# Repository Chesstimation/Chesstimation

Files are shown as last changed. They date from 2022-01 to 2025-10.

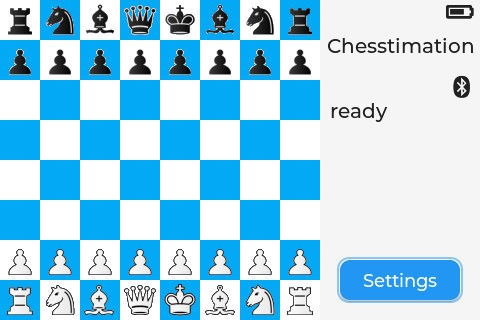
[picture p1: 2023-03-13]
images/main-screen.jpg

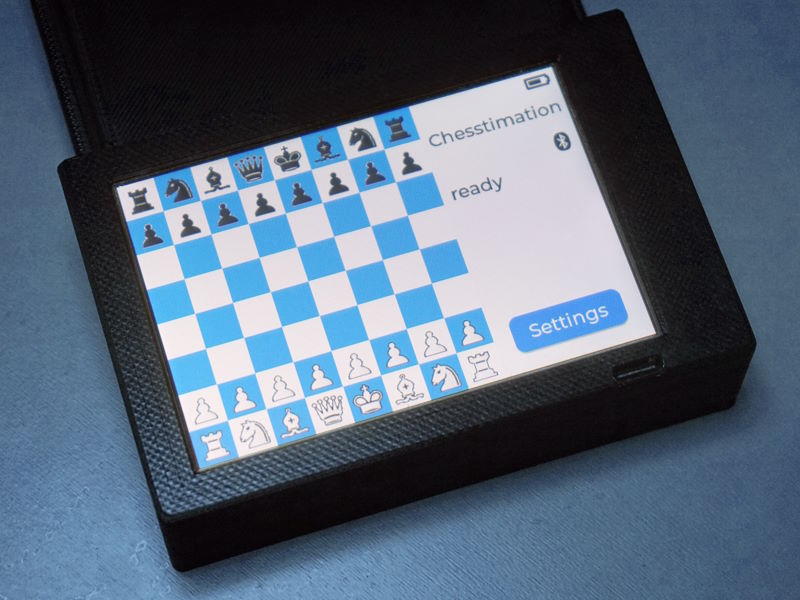
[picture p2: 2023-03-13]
images/module-detail.jpg

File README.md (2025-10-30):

**English** | [Deutsch](./README_de.md) |

# Chesstimation

This project uses ESP32 hardware to connect an old Hegener+Glaser Mephisto Modular chess computer (Modular, Exclusive or München Board) to a computer or a smart phone.

## Main Features:

* No modification to original Mephisto Modular/Exclusive/München board required. Just replace the old modules with the new one!
* 3.5" Color-TFT (480x320 Pixels), available space is perfectly used.
* Modern, intuitive touch control
* Current position is shown on the display.
* Both White and Black can be played from the front.
* All opponent's moves are displayed via the board's LEDs.
* Power supply via built-in battery that can be charged via USB-C (with 2200 mAh lipo >7h running time, ~4h charging time). 
* Communication with PC via USB-C, Bluetooth Classic or BLE (Bluetooth Low Energy).
* Playing completely without cables is possible!
* All settings and the board position are not lost when the device is switched off!
* Switching on and off takes less than 2 seconds.
* Certabo or Millennium Chesslink can be selected as emulation, making it compatible with many chess programs:
  * "White Pawn" on iPhone and Android (https://khadimfall.com/p/white-pawn)
  * "Chess for Android"
  * "Chess Dojo App" for Android
  * BearChess (http://www.solanosoft.com/index.php?page=bearchess)
  * original Certabo Software (https://www.certabo.com/)
  * Lucas Chess (https://lucaschess.pythonanywhere.com/index?lang=en)
  * and via Graham's DLLs (https://goneill.co.nz/chess.php) actually all software that can handle DGT boards.
* Pawn underpromotion selection when reaching second last row

## Limitations:

* Captured piece needs to be removed from board before capturing piece is put to the square. 
* Must not be combined with other modules or power supplies.

## Contact & Donation:

If you like this project you may contact me via chesstimation@kabelmail.de

I would also be happy to receive a donation. 



## Following hardware components are required:
1. Wemos LolinD32 (https://de.aliexpress.com/item/32808551116.html)
2. 40-pin edge card connector, e.g. https://de.aliexpress.com/item/33035971298.html (you need to select 2x20 Pin)
3. Rainbow Ribbon Cable (~30cm) with 1.27mm spacing, e.g. from Aliexpress: https://www.aliexpress.com/item/1005002509747445.html (you need to select 1.27mm spacing and 40 pin!)
4. Waveshare 3.5 inch TFT Pico Res Touch display: https://www.waveshare.com/pico-restouch-lcd-3.5.htm, e.g available here: https://eckstein-shop.de/WaveShare35inchTouchDisplayModuleforRaspberryPiPico2C65KColors2C480C3973202CSPI
5. Micro USB soldering plug (https://www.aliexpress.com/item/33060931097.html) and USB-C female soldering connector (e.g. https://www.aliexpress.com/item/1005002292881776.html) 
6. optionally lipo battery with plug for Lolin D32, e.g.: https://www.aliexpress.com/item/1005001310592871.html (you need an extra JST PH 2.0mm plug for this battery, e.g. https://www.aliexpress.com/item/1005001315857869.html Double-check polarity of plug with + and - signs on PCB of Lolin!) 
7. Micro-Switch (built into bottom of module) to switch off module completely (https://www.aliexpress.com/item/4001202080623.html Choose MSS-22D18 type!) 

## How to connect the 40-pin plug to the Mephisto board?

If you look at the chessboard or module from the front, the upper row of contacts is numbered from left to right from 1 to 39, the lower row from 2 to 40.
With the ribbon cable connector as linked above the wires are numbered a bit different, from left to right: 2,1, 4,3, 6,5, 8,7, ... 40,39.
This has already been considered in below table and you will be able to connect the 8 data wires just in parallel to the Lolin D32.

 <table>
  <tr>
    <th>40-pin Connector Pin</th>
    <th>LolinD32 Pin</th>
  </tr>
  <tr>
    <td>1+2</td>
    <td>BAT</td>
  </tr>
  <tr>
    <td>39+40</td>
    <td>GND</td>
  </tr>
  <tr>
    <td>15 / D0</td>
    <td>GPIO 12</td>
  </tr>
  <tr>
    <td>16 / D1</td>
    <td>GPIO 13</td>
  </tr>
  <tr>
    <td>17 / D2</td>
    <td>GPIO 27</td>
  </tr>
  <tr>
    <td>18 / D3</td>
    <td>GPIO 14</td>
  </tr>
  <tr>
    <td>19 / D4</td>
    <td>GPIO 25</td>
  </tr>
  <tr>
    <td>20 / D5</td>
    <td>GPIO 26</td>
  </tr>
  <tr>
    <td>21 / D6</td>
    <td>GPIO 32</td>
  </tr>
  <tr>
    <td>22 / D7</td>
    <td>GPIO 33</td>
  </tr>
  <tr>
    <td>29 / LDC_LE</td>
    <td>GPIO 2</td>
  </tr>
  <tr>
    <td>30 / ROW_LE</td>
    <td>GPIO 15</td>
  </tr>
  <tr>
    <td>31 / CB_EN</td>
    <td>GPIO 4</td>
  </tr>
  <tr>
    <td>32 / LDC_EN</td>
    <td>GPIO 0</td>
  </tr>
</table> 

## How to connect the 3.5" display to Lolin D32

 <table>
  <tr>
    <th>TFT Display Pin</th>
    <th>LolinD32 Pin</th>
  </tr>
  <tr>
    <td>VSYS</td>
    <td>BAT</td>
  </tr>
  <tr>
    <td>GND</td>
    <td>GND</td>
  </tr>
  <tr>
    <td>LCD_DC</td>
    <td>GPIO 17</td>
  </tr>
  <tr>
    <td>LCD_CS</td>
    <td>SS/GPIO 5</td>
  </tr>
  <tr>
    <td>CLK</td>
    <td>SCK/GPIO 18</td>
  </tr>
  <tr>
    <td>MOSI</td>
    <td>MOSI/GPIO 23</td>
  </tr>
  <tr>
    <td>MISO</td>
    <td>MISO/GPIO 19</td>
  </tr>
  <tr>
    <td>LCD_BL</td>
    <td>GPIO 16</td>
  </tr>
  <tr>
    <td>LCD_RST</td>
    <td>RST(RESET)</td>
  </tr>
  <tr>
    <td>TP_CS</td>
    <td>GPIO 21</td>
  </tr>
  <tr>
    <td>TP_IRQ</td>
    <td>GPIO 34</td>
  </tr>
</table> 

## Software development environment

Software development is done in C++ using:
* Visual Studio Code
* Platform IO

In Platform IO you need to install 2 additional libraries for this project:
* LVGL 8.3.4 (you need to use Chesstimation's lv_conf.h)
* TFT eSPI 2.5.2 (you need to use Chesstimation's as User_Setup.h and User_Setup_Select.h)

For flashing the firmware to the Lolin D32 without Platform IO I use ESP Flasher: https://github.com/Jason2866/ESP_Flasher/releases

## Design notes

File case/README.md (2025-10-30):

**English** | [Deutsch](./README_de.md) |

# 3D-printable case for Open Mephisto

In this directory you find five different STL file to print your Open Mephisto module and matching blank modules.

For the Open Mephisto Module I use:
* ...BASE.stl
* ...DISPLAY.stl
* ...COVER.stl

For each matching blank module I use:
* ...BASE.stl
* ...DISPLAY-VOID.stl
* ...COVER-SNAP.stl

## Print Settings:

* Material: PLA
* Slice thickness: 0.2 mm first slice, 0.15 mm all other slices
* Support needed for ...BASE.stl only

## Donation:

If you like this project, I would be happy to receive a donation. 



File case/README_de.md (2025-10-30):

**Deutsch** | [English](./README.md) |

# 3D-Druckdateien für Open Mephisto

Hier findet ihr fünf verschiedene Dateien um die Teile für das Modul und auch entsprechende Leermodule zu drucken.
Die Module passen in Modular-, Exclusive- und München-Bretter.

Für das eigentliche Modul verwende ich die folgenden 3 Dateien:
* ...BASE.stl
* ...DISPLAY.stl
* ...COVER.stl

Für Leermodule verwende ich die folgenden 3 Dateien:
* ...BASE.stl
* ...DISPLAY-VOID.stl
* ...COVER-SNAP.stl

## Druckeinstellungen:

* Material: PLA
* Schichtdicke ist 0,2 mm für die erste Schicht, für alle weiteren Schichten 0,15 mm
* Support Material wird nur für den Druck von ...BASE.stl benötigt.

## Spenden:

Falls euch das Projekt gefällt, würde ich mich über Spenden sehr freuen:



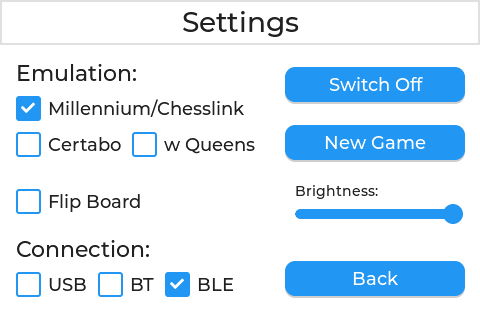
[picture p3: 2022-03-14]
images/settings-screen.jpg

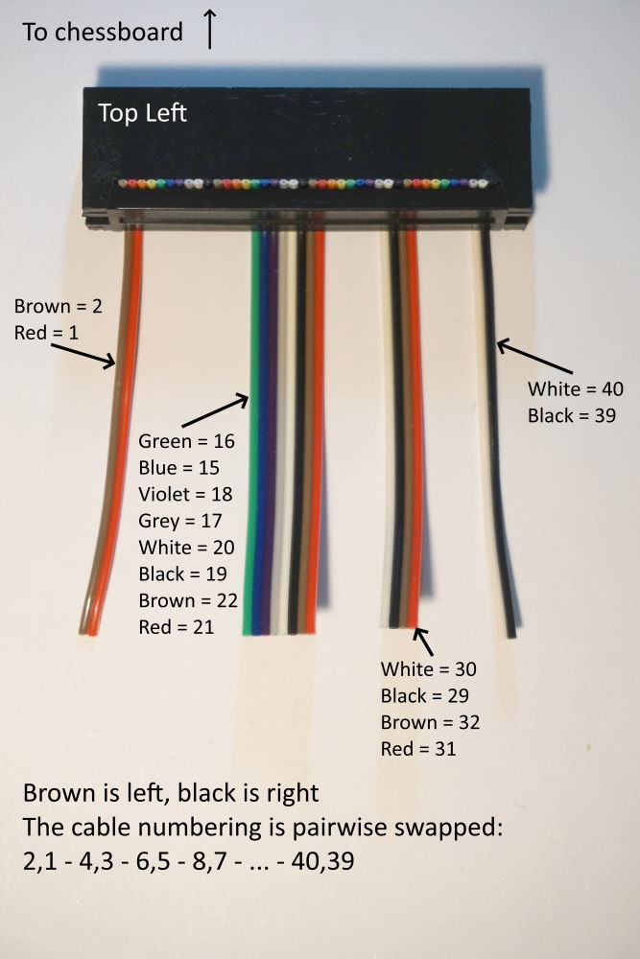
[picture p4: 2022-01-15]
images/40-pin-to-lolind32.jpg

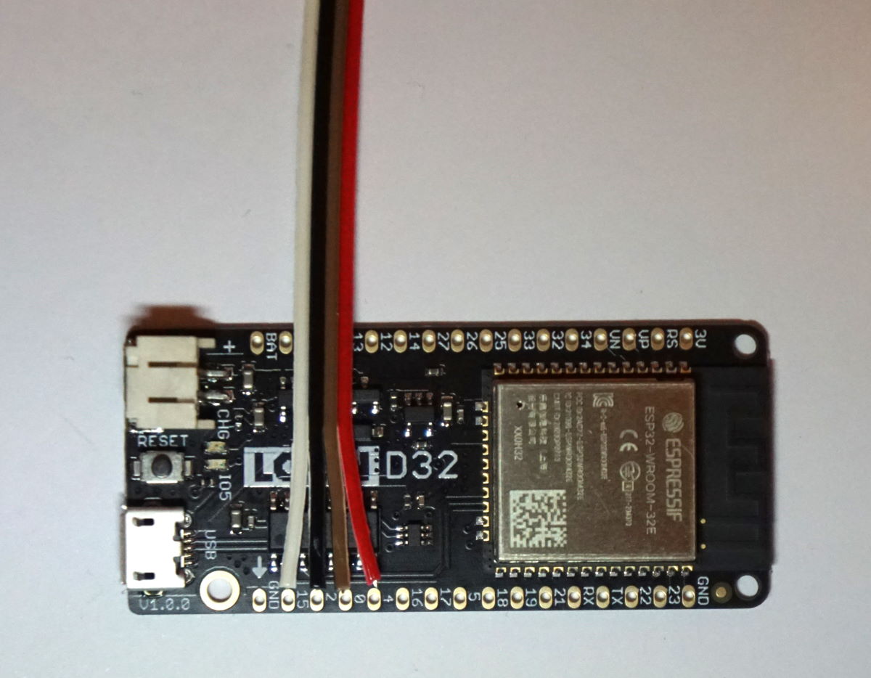
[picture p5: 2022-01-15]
images/control-to-lolinD32.jpg

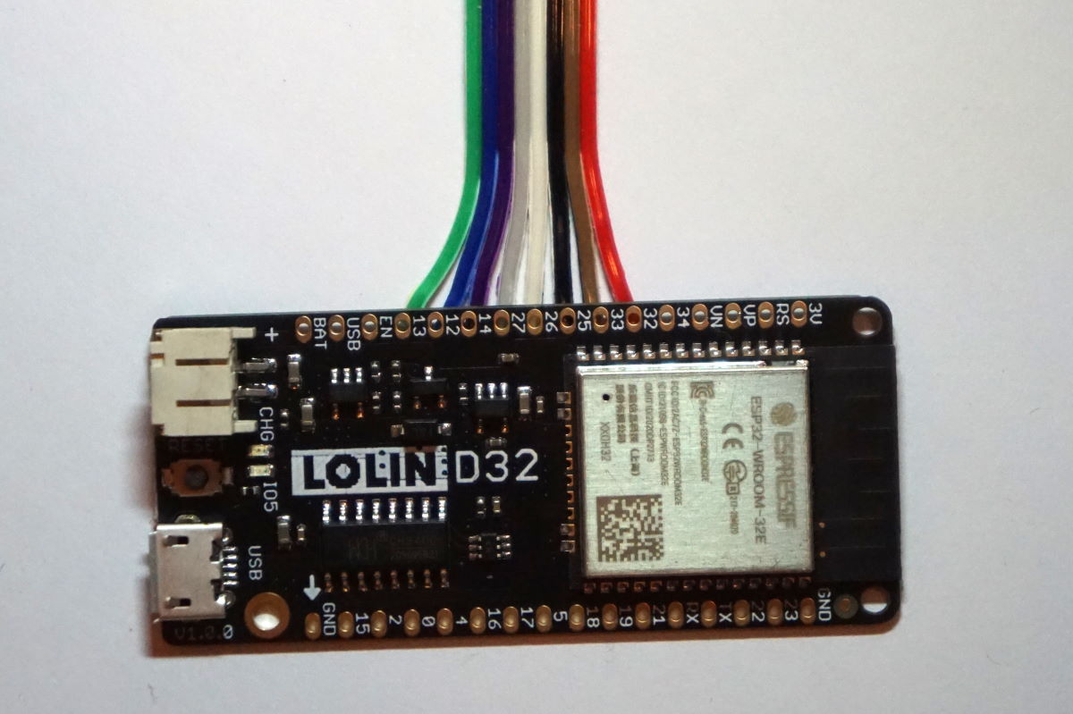
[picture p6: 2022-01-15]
images/data-to-lolinD32.jpg

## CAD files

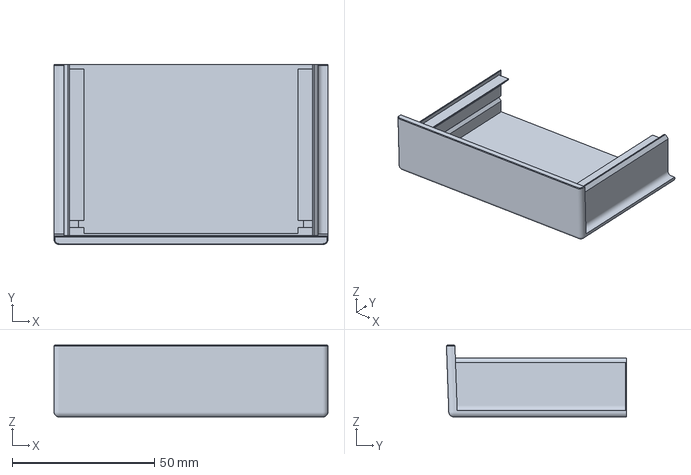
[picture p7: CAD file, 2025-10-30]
case/open-mephisto-module-tft-35-pi-pico-DISPLAY-VOID.3mf
96.4 x 63.4 x 25.3 mm

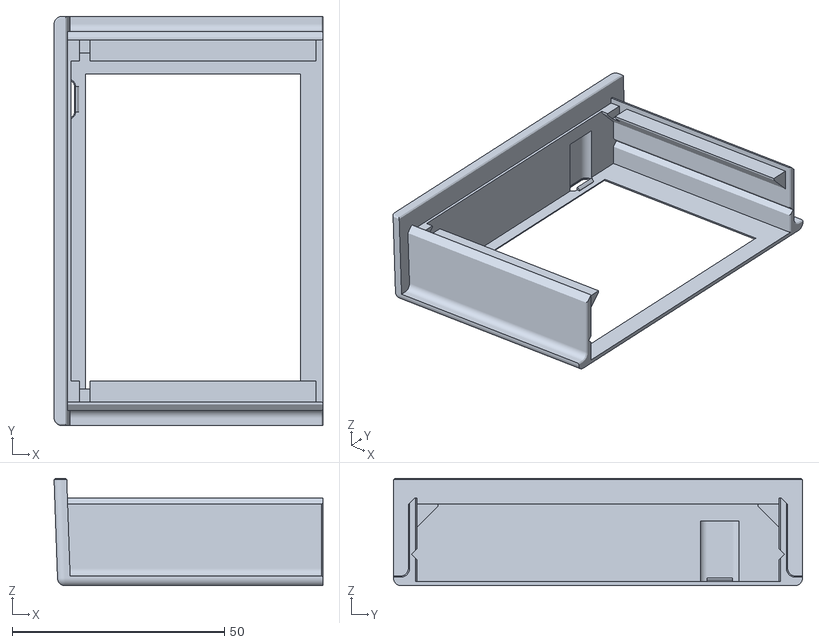
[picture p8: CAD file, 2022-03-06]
case/open-mephisto-module-tft-35-pi-pico-display.stl
63.4 x 96.4 x 25.3

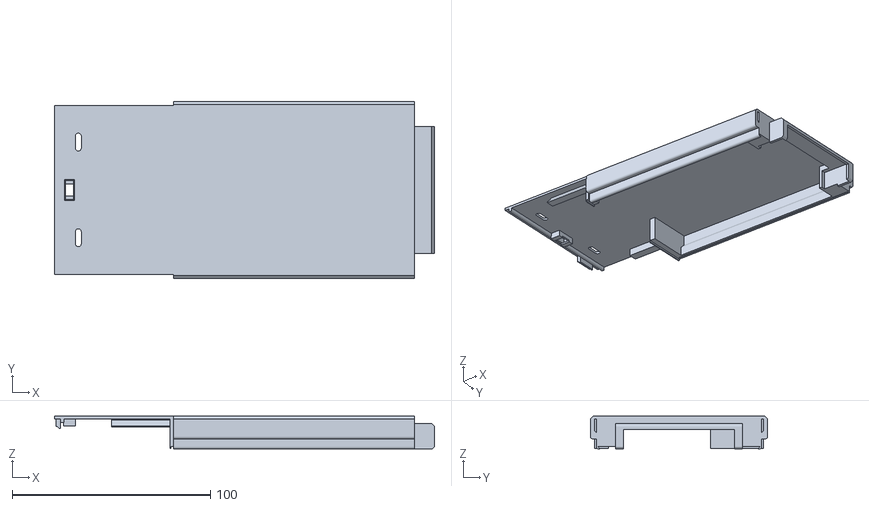
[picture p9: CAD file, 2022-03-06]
case/open-mephisto-module-tft-35-pi-pico-BASE.stl
191.5 x 89.4 x 16.6

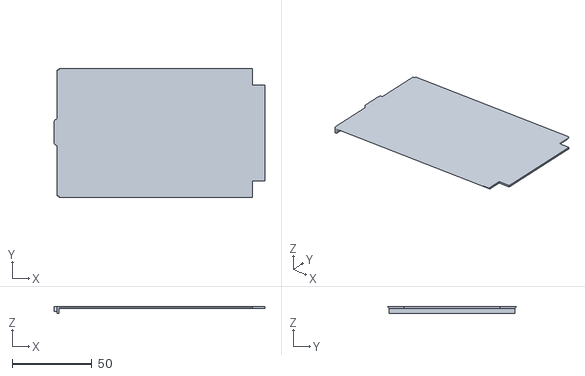
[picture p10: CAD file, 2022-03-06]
case/open-mephisto-module-tft-35-pi-pico-cover.stl
132.7 x 81.2 x 4.20

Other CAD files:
case/DISPLAY-VOID-normal.3mf
case/DISPLAY-VOID-fuzzy.3mf
case/open-mephisto-module-tft-35-pi-pico-COVER-SNAP.stl
case/open-mephisto-module-tft-35-pi-pico-DISPLAY-VOID.stl

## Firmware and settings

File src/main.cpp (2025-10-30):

/*  
    Copyright 2021, 2022, 2023, 2024, 2025 Andreas Petersik (andreas.petersik@gmail.com)
    
    This file is part of the Chesstimation Project.

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
    You should have received a copy of the GNU General Public License
    along with Chesstimation.  If not, see <https://www.gnu.org/licenses/>.
*/

#define VERSION     "Chesstimation 1.7.1"
#define ABOUT_TEXT  "\nby Dr. Andreas Petersik\nandreas.petersik@gmail.com\n\nbuilt: Oct 30th, 2025"
// #define BOARD_TEST

#include <Arduino.h>
#include <SPIFFS.h>
#include <esp_sleep.h>
#include <driver/rtc_io.h>
#include <driver/adc.h>
#include <BluetoothSerial.h>
#include "lv_i18n.h"

#include <BLEDevice.h>
#include <BLE2902.h>
#include "BLEHIDDevice.h"

// For emulations:
#include <thread>
#include <chrono>

// my includes:

#include <mephisto.h>
#include <board.h>

#include "SPI.h"
#include "TFT_eSPI.h"

#include "../lvgl/src/lvgl.h"

#define LOLIN_D32
#define LED_TIME 300
#define MIN_BRIGHTNESS 190

#define TOUCH_PANEL_IRQ_PIN   GPIO_NUM_34   // The idea is to check if there is a signal change on this pin for waking ESP32 from sleep! Works! Pin is high when no touch, low when touch!

#define BOARD_SETUP_FILE  "/board_setup"
#define SQUARE_SIZE         40

// #define PEGASUS

Mephisto mephisto;
Board chessBoard;
BluetoothSerial SerialBT;

char modeBleAdvertisedName[] = "MILLENNIUM CHESS";

int millBLEinitialized = 0;
int physicalConformity = 0;

enum connectionType {USB, BT, BLE} connection;  // Should be same order as in UI
enum languageType {EN, ES, DE} language;        // Should be same order as in UI

byte readRawRow[8];
byte led_buffer[8];
byte mephistoLED[8][8];
byte eeprom[5]={0,20,3,20,15};
byte LED_startup_sequence[64] = {0,1,2,3,4,5,6,7,15,23,31,39,47,55,63,62,61,60,59,58,57,56,48,40,32,24,16,8, 9,10,11,12,13,14,22,30,38,46,54,53,52,51,50,49,41,33,25,17, 18,19,20,21,29,37,45,44,43,42,34,26, 27,28,36,35};
byte oldBoard[64];
int brightness = 255;

uint16_t calibrationData[5];

//BLE objects
BLEServer *pServer = NULL;
BLECharacteristic *pTxCharacteristic;
BLEService *pService;

SemaphoreHandle_t sendBLEsemaphore = NULL;

char incomingMessage[170];
std::string replyString;

TFT_eSPI tft = TFT_eSPI();

/*Set to your screen resolution*/
#define TFT_HOR_RES   480
#define TFT_VER_RES   320

/*LVGL draw into this buffer, 1/10 screen size usually works well. The size is in bytes*/
#define DISP_BUF_SIZE (320 * 96)
// #define DISP_BUF_SIZE (320 * 60) // old size used for LVGL 8.x
// #define DISP_BUF_SIZE (TFT_HOR_RES * TFT_VER_RES / 6 * (LV_COLOR_DEPTH / 8)) // leads to not working White Pawn
// lv_color_t *dispBuf;//[DISP_BUF_SIZE]; 
void *dispBuf;//[DISP_BUF_SIZE]; 

lv_display_t * disp;

lv_style_t fMediumStyle;
lv_style_t fLargeStyle;
lv_style_t fExtraLargeStyle;
lv_style_t light_square;
lv_style_t dark_square;

LV_FONT_DECLARE(montserrat_umlaute20);
LV_FONT_DECLARE(montserrat_umlaute22);
LV_IMG_DECLARE(WP40);
LV_IMG_DECLARE(BP40);
LV_IMG_DECLARE(WK40);
LV_IMG_DECLARE(BK40);
LV_IMG_DECLARE(WB40);
LV_IMG_DECLARE(BB40);
LV_IMG_DECLARE(WQ40);
LV_IMG_DECLARE(BQ40);
LV_IMG_DECLARE(WN40);
LV_IMG_DECLARE(BN40);
LV_IMG_DECLARE(WR40);
LV_IMG_DECLARE(BR40);

lv_indev_t * indev;

lv_obj_t *settingsScreen, *settingsBtn, *btn2, *screenMain, *liftedPiecesLbl, *liftedPiecesStringLbl, *debugLbl, *chessBoardCanvas, *chessBoardLbl, *batteryLbl;
lv_obj_t *labelA1, *exitSettingsBtn, *offBtn, *certaboCalibCB, *restartBtn, *certaboCB, *chesslinkCB, *languageLbl, *flippedCB, *pegasusCB, *testCB;
lv_obj_t *square[64], *dummy1Btn, *calibrateBtn, *object, *brightnessSlider, *connectionLbl, *commLbl, *emulatorsBtn, *langBtn, *langLbl;
lv_obj_t *ui_settings_obj, *offBtnLbl, *newGameLbl, *brightLbl, *backLbl, *settingsLbl, *emulationLbl, *langDd, *connectionDd;
lv_obj_t *promotionBtnW, *promotionBtnImageW, *promotionBtnB, *promotionBtnImageB;
lv_obj_t *wp[8], *bp[8], *wk, *bk, *wn1, *bn1, *wn2, *bn2, *wb1, *bb1, *wb2, *bb2, *wr1, *br1, *wr2, *br2, *wq1, *bq1, *wq2, *bq2;

void displayLEDstartUpSequence()
{
  for(int i=0; i<64; i++)
  {
    mephisto.writeRow(getRowFromBoardIndex(LED_startup_sequence[i]), 0x1 << getColFromBoardIndex(LED_startup_sequence[i]));
    delay(48);
  }
}

void assembleIncomingChesslinkMessage(char readChar)
{
  switch (readChar)
  {
  case 'R':
  case 'I':
  case 'L':
  case 'V':
  case 'W':
  case 'S':
  case 'X':
    incomingMessage[0] = readChar;
    incomingMessage[1] = 0;
    break;
  default:
    byte position = strlen(incomingMessage);
    incomingMessage[position] = readChar;
    incomingMessage[position + 1] = 0;
    break;
  }
}

void displayAboutBox()
{
  object = lv_msgbox_create(screenMain);

  lv_msgbox_add_title(object, VERSION);
  lv_msgbox_add_text(object, ABOUT_TEXT);
  lv_msgbox_add_close_button(object);

  lv_obj_add_style(object, &fLargeStyle, 0);
  lv_obj_set_size(object, 368, 186);
  lv_obj_center(object);
  lv_obj_clear_flag(object, LV_OBJ_FLAG_SCROLLABLE);
}

byte debugPrint(const char *message)
{
  if(connection != USB) 
  {
    Serial.print(message);
    return 1;
  }
  if(connection != BT) 
  {
    SerialBT.print(message);
    return 1;
  }
  return 0;
}

void startTouchCalibration()
{
    // object = lv_msgbox_create(NULL, "Touch Calibration", "Touch the corners with the white line\nin counter clockwise order", NULL, true);

    // lv_obj_add_style(object, &fLargeStyle, 0);
    // lv_obj_set_size(object, 480, 320);
    // lv_obj_center(object);
    // lv_obj_clear_flag(object, LV_OBJ_FLAG_SCROLLABLE);

    tft.calibrateTouch(calibrationData, TFT_WHITE, TFT_RED, 15);
    tft.fillRect(480-16, 320-16, 16, 16, TFT_RED);

    lv_obj_invalidate(settingsScreen);

    // lv_obj_add_flag(object, LV_OBJ_FLAG_HIDDEN);
}

byte debugPrintln(const char *message)
{
  if(connection != USB) 
  {
    Serial.println(message);
    return 1;
  }
  if(connection != BT) 
  {
    SerialBT.println(message);
    return 1;
  }
  return 0;
}

void saveBoardSettings(void)
{
  connectionType saveConnection = USB;

  if (!SPIFFS.begin())
  {
    SPIFFS.format();
    SPIFFS.begin();
  }

  if ((connection == BLE) && (chessBoard.emulation != 0))
  {
    saveConnection = BLE;
  }
  if (connection == BT)
  {
    saveConnection = BT;
  }

  // store data
  File f = SPIFFS.open(BOARD_SETUP_FILE, "w");
  if (f)
  {
    f.write((const byte *)chessBoard.piece, 64);
    f.write((const byte *)chessBoard.piecesLifted, 64);
    f.write(chessBoard.liftedIdx);
    f.write(chessBoard.emulation);
    f.write(chessBoard.flipped);
    f.write(saveConnection);
    f.write(brightness);
    f.write(language);
    f.close();
  }
}

void loadBoardSettings(void)
{

  byte tempBoardSetup[64];
  uint16_t tempPiecesLifted[32];
  uint8_t tempInt8[1];
  physicalConformity = 1;

  if (!SPIFFS.begin())
  {
    SPIFFS.format();
    SPIFFS.begin();
  }

  // check if file exists
  if (SPIFFS.exists(BOARD_SETUP_FILE))
  {
    File f = SPIFFS.open(BOARD_SETUP_FILE, "r");
    if (f)
    {
      if (f.readBytes((char *)tempBoardSetup, 64) == 64)
      {
        for (int i = 0; i < 64; i++)
        {
          chessBoard.piece[i] = tempBoardSetup[i];
        }
      }
      if (f.readBytes((char *)tempPiecesLifted, 64) == 64)
      {
        for (int i = 0; i < 32; i++)
        {
          chessBoard.piecesLifted[i] = tempPiecesLifted[i];
        }
      }
      if (f.readBytes((char *)tempInt8, 1) == 1)
      {
        chessBoard.liftedIdx = tempInt8[0];
      }
      if (f.readBytes((char *)tempInt8, 1) == 1)
      {
        chessBoard.emulation = tempInt8[0];
      }
      if (f.readBytes((char *)tempInt8, 1) == 1)
      {
        chessBoard.flipped = tempInt8[0];
      }
      if (f.readBytes((char *)tempInt8, 1) == 1)
      {
        connection = (connectionType)tempInt8[0];
      }
      if (f.readBytes((char *)tempInt8, 1) == 1)
      {
        if(tempInt8[0] < MIN_BRIGHTNESS)
        {
          brightness = MIN_BRIGHTNESS;
        }
        else
        {
          brightness = tempInt8[0];
        }
      }
      if (f.readBytes((char *)tempInt8, 1) == 1)
      {
        language = (languageType)tempInt8[0];
      }
      f.close();
    }
  }
}

void updateMephistoLEDs(byte mephistoLED[8][8]) {
  for(byte row=0; row<8; row++) {
    for(byte col=0; col<8; col++) {
      mephistoLED[col][row]=chessBoard.milleniumLEDs[col][row] & chessBoard.milleniumLEDs[col+1][row]
        & chessBoard.milleniumLEDs[col][row+1] & chessBoard.milleniumLEDs[col+1][row+1];
    }
  }
}

byte getOddParity(byte value)
{
  value ^= value >> 4;
  value ^= value >> 2;
  value ^= value >> 1;
  return (~value) & 1;
}

void sendMessageToChessBoard(const char *message)
{
  std::string codedMessage = message;
  char blockCode[3];

  debugPrintln("Message to be sent from Board to Application: ");
  debugPrintln(message);

  if (chessBoard.emulation == 1)
  {
    sprintf(blockCode, "%02X", chessBoard.calcBlockPar(message));
    codedMessage += blockCode;
  }

  if (connection == BLE)
  {

    for (int i = 0; i < codedMessage.length(); i++)
    {
      if (getOddParity(codedMessage[i]))
      {
        codedMessage[i] += 128;
      }
    }
    // debugPrint("Final Message to be sent: ");
    // debugPrintln(codedMessage.c_str());

    if (xSemaphoreTake(sendBLEsemaphore, portMAX_DELAY) == pdTRUE)
    {
      for (int i = 0; i < codedMessage.length(); i += 8)
      {
        pTxCharacteristic->setValue(codedMessage.substr(i, 8));
        pTxCharacteristic->notify();
      }
      xSemaphoreGive(sendBLEsemaphore);
    }
    else
    {
      debugPrintln("*** Semaphore could not be taken - ERROR sending message ***");
    }
  }
  if (connection == BT)
  {
    SerialBT.print(codedMessage.c_str());
    SerialBT.flush();
  }
  if (connection == USB)
  {
    Serial.print(codedMessage.c_str());
    Serial.flush();
  }
}

void updateSettingsScreen()
{
  if(chessBoard.emulation==0) 
  {
#ifdef PEGASUS
    lv_obj_clear_state(pegasusCB, LV_STATE_CHECKED);  
#endif
    lv_obj_add_state(certaboCB, LV_STATE_CHECKED);
    lv_obj_clear_state(chesslinkCB, LV_STATE_CHECKED);  
  }
  if(chessBoard.emulation==1) 
  {
#ifdef PEGASUS
    lv_obj_clear_state(pegasusCB, LV_STATE_CHECKED);  
#endif
    lv_obj_clear_state(certaboCB, LV_STATE_CHECKED);
    lv_obj_add_state(chesslinkCB, LV_STATE_CHECKED);  
  }
  if(chessBoard.emulation==2) 
  {
    lv_obj_clear_state(certaboCB, LV_STATE_CHECKED);
    lv_obj_clear_state(chesslinkCB, LV_STATE_CHECKED);
#ifdef PEGASUS
    lv_obj_add_state(pegasusCB, LV_STATE_CHECKED);  
#endif
  }
  if(chessBoard.flipped) 
  {
    lv_obj_add_state(flippedCB, LV_STATE_CHECKED);
  }
  if(!chessBoard.flipped) 
  {
    lv_obj_clear_state(flippedCB, LV_STATE_CHECKED);
  }
}

class MyServerCallbacksPegasus : public BLEServerCallbacks
{
  void onConnect(BLEServer *pServer)
  {
    connection = BLE;
    updateSettingsScreen();
    debugPrintln("Pegasus Emulation: BLE DEVICE CONNECTED");
  };

  void onDisconnect(BLEServer *pServer)
  {
    debugPrintln("Pegasus Emulation: BLE DEVICE DISCONNECTED");
    updateSettingsScreen();
    delay(500);                  // give the bluetooth stack the chance to get things ready
    pServer->startAdvertising(); // restart advertising
  }
};

class MyServerCallbacks : public BLEServerCallbacks
{
  void onConnect(BLEServer *pServer)
  {
    connection = BLE;
    updateSettingsScreen();
    debugPrintln("Millennium Emulation: BLE DEVICE CONNECTED");
  };

  void onDisconnect(BLEServer *pServer)
  {
    debugPrintln("Millennium Emulation: BLE DEVICE DISCONNECTED");
    millBLEinitialized = 0;
    updateSettingsScreen();
    delay(500);                  // give the bluetooth stack the chance to get things ready
    pServer->startAdvertising(); // restart advertising
  }
};
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
void loop()
{
  byte rows = 0;
  byte setBack = 0;
  byte lifted = 0;
  static byte writeToIndex = 0;

#ifdef LOLIN_D32
  static long long oldMillis=-10000;
  static long long oldMessageMillis=-10000;
  unsigned long actMillis;
  actMillis = millis();
  static unsigned long lastTickMillis = 0;
  
    // LVGL Tick Interface, this is required since LVGL 9.x
  unsigned int tickPeriod = actMillis - lastTickMillis;
  lv_tick_inc(tickPeriod);
  lastTickMillis = actMillis;

  if(actMillis-oldMillis>10000) {
    float voltage = analogRead(35)/587.5;
    // char batMessage[80]="";
    // sprintf(batMessage, "%.2fV - %1.0f min", voltage, actMillis/60000.0);
    // lv_label_set_text(debugLbl, batMessage);
    // debugPrintln(batMessage);
    if(voltage > 3.79)
    {
      lv_label_set_text(batteryLbl, LV_SYMBOL_BATTERY_FULL);
    }
    else if(voltage > 3.56)
    {
      lv_label_set_text(batteryLbl, LV_SYMBOL_BATTERY_3);
    }
    else if(voltage > 3.46)
    {
      lv_label_set_text(batteryLbl, LV_SYMBOL_BATTERY_2);
    }
    else if(voltage > 3.35)
    {
      lv_label_set_text(batteryLbl, LV_SYMBOL_BATTERY_1);
    }
    else
    {
      lv_label_set_text(batteryLbl, LV_SYMBOL_BATTERY_EMPTY);
    }
    oldMillis=actMillis;
  }
#endif  

  lv_task_handler();

#ifdef BOARD_TEST
  if ((lv_obj_get_state(testCB) & LV_STATE_CHECKED) == 1)
  {
    static int i = 0;
    {
      mephisto.writeRow(i, 0xff);
      delay(500);
      lv_task_handler();

      mephisto.writeRow(i, 0x00);
      delay(100);
      lv_task_handler();
      int value = mephisto.readRow(i);
      if(1)//value != 0)
      {
        mephisto.writeRow(i, value);
        delay(500);
      }
    }
    i++;
    if (i > 7)
      i = 0;
    return;
  }
#endif

  if (chessBoard.emulation == 0) // Certabo!
  {
    if (connection == USB)
    {
      while (Serial.available())
      {
        led_buffer[writeToIndex] = Serial.read();

        writeToIndex++;
        if (writeToIndex > 7)
        {
          writeToIndex = 0;
          Serial.println("L");
          Serial.flush();
        }
      };
    }
    if (connection == BT)
    {
      while (SerialBT.available())
      {
        led_buffer[writeToIndex] = SerialBT.read();

        writeToIndex++;
        if (writeToIndex > 7)
        {
          writeToIndex = 0;
          SerialBT.println("L");
          SerialBT.flush();
        }
      };
    }
  }

  if ((chessBoard.emulation == 1) && connection != BLE) // Millennium Chesslink
  {
    char readChar;
    if (connection == USB)
    {
      if (Serial.available() > 0)
      {
        for (int i = 0; i < Serial.available(); i++)
        {
          Serial.readBytes(&readChar, 1);

          assembleIncomingChesslinkMessage(readChar);
        }
        sendChesslinkAnswer(incomingMessage);
      }
    }
    if (connection == BT)
    {
      if (SerialBT.available() > 0)
      {
        for (int i = 0; i < SerialBT.available(); i++)
        {
          SerialBT.readBytes(&readChar, 1);

          assembleIncomingChesslinkMessage(readChar);
        }
        sendChesslinkAnswer(incomingMessage);
      }
    }
  }

  if(chessBoard.emulation==1) // Millennium Chesslink
  {
    // Translate MephistoLEDs into led_buffer:

    for (byte row = 0; row < 8; row++)
    {
      byte rowValue = 0;
      for (byte col = 0; col < 8; col++)
      {
        byte led = 0;
        if (mephistoLED[7 - col][row] > 0)
          led = 1;
        rowValue <<= 1;
        rowValue += led;
      }
      led_buffer[row] = rowValue;
    }
  }

  // Read row status from board:
  for(int i=0; i<8; i++) {
    readRawRow[i] = mephisto.readRow(i);
  }

  // Check physical conformity (this is only done when a new game is started):
  if (!physicalConformity)
  {
    byte piecesPhys, piecesMem;
    char debugMessage[80] = "";
    rows = 0;

    for (int row = 0; row < 8; row++)
    {
      piecesMem = 0;
      for (int i = 0; i < 8; i++)
      {
        piecesMem <<= 1;
        if (chessBoard.piece[toBoardIndex(row, i)] != 0)
        {
          piecesMem++;
        }
      }

      piecesPhys = readRawRow[row];

      sprintf(debugMessage, "piecesPhysical: %x", piecesPhys);
      debugPrintln(debugMessage);
      sprintf(debugMessage, "piecesMemory: %x", piecesMem);
      debugPrintln(debugMessage);

      if (piecesMem != piecesPhys)
      {
        physicalConformity = 0;
        rows++;
        lv_label_set_text_fmt(debugLbl, lv_i18n_get_text("UI_CHECK_PIECES"));
        led_buffer[7-row] = piecesMem>piecesPhys?piecesMem-piecesPhys:piecesPhys-piecesMem;

        // mephisto.writeRow(row, piecesMem>piecesPhys?piecesMem-piecesPhys:piecesPhys-piecesMem);
        // delay(LED_TIME);
      }
    }
    if (rows == 0)
    {
      physicalConformity = 1;
      lv_label_set_text_fmt(debugLbl, "");
      led_buffer[0] = led_buffer[1] = led_buffer[2] = led_buffer[3] = led_buffer[4] = led_buffer[5] = led_buffer[6] = led_buffer[7] = 0; 
    }
    for (int i = 0; i < 8; i++)
    {
      mephisto.writeRow(7 - i, led_buffer[i]);
      if (led_buffer[i] != 0 && rows != 0)
      {
        delay(LED_TIME / rows);
        lv_task_handler();
      }
    }
    return;
  }

  // First step: Display LEDs with the content from the buffer.
  // 1st calculate buffer time:
  rows = 0;
  for (int i = 0; i < 8; i++)
  {
    if (led_buffer[i] != 0)
      rows++;
  }

  for (int i = 0; i < 8; i++)
  {
    // bit wise reverse taken from: http://graphics.stanford.edu/~seander/bithacks.html#BitReverseObvious
    byte ledValue = chessBoard.flipped ? (led_buffer[7 - i] * 0x0202020202ULL & 0x010884422010ULL) % 1023 : led_buffer[i];
    mephisto.writeRow(7 - i, ledValue);
    if (ledValue != 0)
      delay(LED_TIME / rows);
  }

  setBack = 0;
  lifted = 0;

  // Check every single field for lifted piece:
  for(int i=0; i<8; i++) { // for each row
    for(int col = 0; col<8; col++) { // for each column
    int diff = (bitRead(chessBoard.lastRawRow[i], col) - bitRead(readRawRow[i], col));
      if(diff>0) {
        chessBoard.liftPieceFrom(toBoardIndex(i, col));
        lifted++;
        lv_label_set_text_fmt(debugLbl, "Lifted row: %i", getRowFromBoardIndex((chessBoard.piecesLifted[chessBoard.liftedIdx - 1] >> 8)));
      }
    }
  }

  // Check every single field for set back piece:
  // for each row
  for (int i = 0; i < 8; i++)
  { 
    // for each column
    for (int col = 0; col < 8; col++)
    { 
      int diff = (bitRead(chessBoard.lastRawRow[i], col) - bitRead(readRawRow[i], col));
      if (diff < 0)
      {
        chessBoard.setPieceBackTo(toBoardIndex(i, col));
        setBack++;
      }
    }
  }

  // A figure was lifted or set back:
  if (lifted + setBack > 0)
  {
    chessBoard.updateLiftedPiecesString();
    if (chessBoard.liftedIdx == 0)
    {
      lv_label_set_text(debugLbl, "");
      lv_label_set_text(liftedPiecesStringLbl, "");
    }
    else
    {
      lv_label_set_text_fmt(debugLbl, "Lifted: %i", chessBoard.liftedIdx);
      lv_label_set_text(liftedPiecesStringLbl, chessBoard.liftedPiecesDisplayString);
    }
    updatePiecesOnBoard();
  }

  for (int row = 0; row < 8; row++)
  {
    chessBoard.lastRawRow[row] = readRawRow[row];
  }

  // Check if promotion button neeed to be enabled:
  int pawnsW = 0;
  int pawnsB = 0;
  for (int col = 0; col < 8; col++)
  {
    if (chessBoard.flipped)
    {
      if (chessBoard.isBlackPawn(chessBoard.piece[toBoardIndex(6, col)]))
        pawnsB++;
      if (chessBoard.isWhitePawn(chessBoard.piece[toBoardIndex(1, col)]))
        pawnsW++;
    }
    else
    {
      if (chessBoard.isWhitePawn(chessBoard.piece[toBoardIndex(6, col)]))
        pawnsW++;
      if (chessBoard.isBlackPawn(chessBoard.piece[toBoardIndex(1, col)]))
        pawnsB++;
    }
  }
  // TODO: Remove debugging:
  // if(pawnsW!=0 || pawnsB!=0)
  //   lv_label_set_text_fmt(debugLbl, "W: %i, B: %i", pawnsW, pawnsB);
  
  if (pawnsW && lv_obj_has_flag(promotionBtnW, LV_OBJ_FLAG_HIDDEN))
  {
    lv_obj_remove_flag(promotionBtnW, LV_OBJ_FLAG_HIDDEN);
  }
  else if (!pawnsW && !lv_obj_has_flag(promotionBtnW, LV_OBJ_FLAG_HIDDEN))
  {
    lv_obj_add_flag(promotionBtnW, LV_OBJ_FLAG_HIDDEN);
  }
  if (pawnsB && lv_obj_has_flag(promotionBtnB, LV_OBJ_FLAG_HIDDEN))
  {
    lv_obj_remove_flag(promotionBtnB, LV_OBJ_FLAG_HIDDEN);
  }
  else if (!pawnsB && !lv_obj_has_flag(promotionBtnB, LV_OBJ_FLAG_HIDDEN))
  {
    lv_obj_add_flag(promotionBtnB, LV_OBJ_FLAG_HIDDEN);
  }

  // After the whole board is read and any change is regarded, the Serial Board message is re-generated:
  chessBoard.generateSerialBoardMessage();
  // if(connection == BLE && chessBoard.emulation==1)
  // {
  //   chessBoard.boardMessage[65]=0;
  // }
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

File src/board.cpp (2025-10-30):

/*  
    Copyright 2021, 2022, 2025 Andreas Petersik (andreas.petersik@gmail.com)
    
    This file is part of the Chesstimation Project.

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
    You should have received a copy of the GNU General Public License
    along with Chesstimation.  If not, see <https://www.gnu.org/licenses/>.
*/

#include "board.h"

byte Board::calcBlockPar(const char *message)
{
    byte blockPar = 0;
    for (int i = 0; i < strlen(message); i++)
    {
        blockPar ^= (byte)(message[i]);
    }
    return blockPar;
}

void Board::extinguishMilleniumLEDs(void) {
    for(byte i=0; i<9; i++) {
        for(byte j=0; j<9; j++) {
            milleniumLEDs[i][j]=0;
        }
    }
}

void Board::updateMilleniumLEDs(const char* ledMessage) {
    uint16_t messageIdx;
    byte high, low, result;
    messageIdx = 2;
    for(byte col=0; col<9; col++) {
        for(byte row=0; row<9; row++) {
            high = low = 0;
            if(ledMessage[messageIdx]>='0' && ledMessage[messageIdx]<='9') high = ledMessage[messageIdx]-48;
            if(ledMessage[messageIdx]>='A' && ledMessage[messageIdx]<='F') high = ledMessage[messageIdx]-55;
            if(ledMessage[messageIdx+1]>='0' && ledMessage[messageIdx+1]<='9') low = ledMessage[messageIdx+1]-48;
            if(ledMessage[messageIdx+1]>='A' && ledMessage[messageIdx+1]<='F') low = ledMessage[messageIdx+1]-55;
            result = (high<<4)+low;
            // if(result==0x55) result = 0x33;
            // if(result==0xFF) result = 0xCC;
            milleniumLEDs[8-col][8-row]=result;
            // if(milleniumLEDs[8-col][8-row]>0) milleniumLEDs[8-col][8-row]=0xFF; // Fix for alternate LED bug in BearChess
            messageIdx+=2;
        }
    }
}

void Board::startPosition(byte queens) {
    byte p[64] = {
        BR1, BN1, BB1, BQ1, BK1, BB2, BN2, BR2,
        BP1, BP2, BP3, BP4, BP5, BP6, BP7, BP8,
        EMP, EMP, EMP, EMP, EMP, EMP, EMP, EMP,
        EMP, EMP, EMP, EMP, EMP, EMP, EMP, EMP,
        EMP, EMP, EMP, EMP, EMP, EMP, EMP, EMP,
        EMP, EMP, EMP, EMP, EMP, EMP, EMP, EMP,
        WP1, WP2, WP3, WP4, WP5, WP6, WP7, WP8,
        WR1, WN1, WB1, WQ1, WK1, WB2, WN2, WR2
    };
    if (queens)
    {
        p[19] = BQ2;
        p[43] = WQ2;
    }
    for(int i=0; i<64; i++) {
        piece[i]=flipped?p[63-i]:p[i];
    }
    // gameIdx=32;
    for(liftedIdx=0; liftedIdx<32; liftedIdx++) {
        piecesLifted[liftedIdx]=EMP;
    }
    liftedIdx = 0;        
}

Board::Board(void) {
    promotionPieceW = promotionPieceB = 'Q';
    boardMessage[0]=0;
    liftedIdx=255;
    startPosition(0);
    lastRawRow [0] = lastRawRow [1] = lastRawRow [6] = lastRawRow [7] = 255; 
    lastRawRow [2] = lastRawRow [3] = lastRawRow [4] = lastRawRow [5] = 0; 
}

void Board::generateSerialBoardMessage(void)
{
    if (emulation == 0)
    {
        // Certabo
        boardMessage[0] = ':';
        boardMessage[1] = 0;
        char number[13];

        for (int i = 0; i < 64; i++)
        {
            if (!flipped)
            {
                sprintf(number, "0 0 0 0 %i ", piece[i]);
            }
            else
            {
                sprintf(number, "0 0 0 0 %i ", piece[63 - i]);
            }
            strcat(boardMessage, number);
        }
        strcat(boardMessage, "\r\n");
    }
    else
    {
        // Chesslink
        boardMessage[0] = 's';

        for (int i = 0; i < 64; i++)
        {
            boardMessage[i + 1] = flipped ? FENpieceFromType(piece[i]) : FENpieceFromType(piece[63 - i]);
        }

        boardMessage[65] = 0;
    }
}

// This function is only for debug purposes and displays the board graphically via the debug serial interface

void Board::printDebugMessage(void) {
    char pieceStr[8]=" ";
    byte pieceType = EMP;

    for(int y=0; y<8; y++) {
        Serial.print("-----------------------------------------\r\n");
        for(int x=0; x<8; x++) {
            pieceType = piece[y*8+x];
            if (pieceType!=EMP) {
                sprintf(pieceStr, "| %2d ", pieceType);
            } else {
                sprintf(pieceStr, "|    ");
            }
            Serial.print(pieceStr);
        }
        Serial.print("|\r\n");
    }
    Serial.print("-----------------------------------------\r\n");

    // Now generate the display of the Lifted Pieces List:
    Serial.print("\r\n");
    for(int i=0; i<32; i++) {
        sprintf(pieceStr, "|%2d", i);
        Serial.print(pieceStr);
    }
     Serial.print("|\r\n");
// //    strcat(boardMessage, "------------------------------------------------------------------------------------------------\r\n");
     for(int i=0; i<32; i++) {
         byte p = 0x00ff & piecesLifted[i];
         if(p!=EMP) {
            sprintf(pieceStr, "|%2d", p);
            Serial.print(pieceStr);
         } else {
             Serial.print("|  ");
         }
     }
     Serial.print("|\r\n");
// //    strcat(boardMessage, "------------------------------------------------------------------------------------------------\r\n");
     for(int i=0; i<32; i++) {
         byte boardIndex = piecesLifted[i]>>8;
         byte p = 0x00ff & piecesLifted[i];
         if(p!=EMP) {
            sprintf(pieceStr, "|%c%1d", 'A'+getColFromBoardIndex(boardIndex), 7-getRowFromBoardIndex(boardIndex)+1);
            Serial.print(pieceStr);
         } else {
             Serial.print("|  ");
         }
     }
     Serial.print("|\r\n\r\n");
    
}

/// @brief 
/// @param piece: representation of piece in internal notation
/// @return FEN code for piece

char Board::FENpieceFromType(byte piece) {
    char fen;
    switch(piece & 0b00001110)
    {
        case 0b0010:
            fen = 'P';
            break;
        case 0b0100:
            fen = 'R';
            break;
        case 0b0110:
            fen = 'N';
            break;
        case 0b1000:
            fen = 'B';
            break;
        case 0b1010:
            fen = 'Q';
            break;
        case 0b1100:
            fen = 'K';
            break;
        default:
            return '.';
    }
    if((piece & 0x01) == 1)
    {
        fen += 32;
    }
    return fen;
}

void Board::updateLiftedPiecesString(void) {
    char piece[2]=" ";
    liftedPiecesDisplayString[0]=0;
    int start = liftedIdx-32;   // max number of pieces which can be displayed
    if(start<0) start = 0;
     for(int i=start; i<32; i++) {
         byte p = 0x00ff & piecesLifted[i];
         piece[0] = FENpieceFromType(p);
         if(piece[0]=='.') return;
         strcat(liftedPiecesDisplayString, piece);
     }
}

bool Board::isWhitePawn(byte piece) {
    if((piece & 0b00001111) == 0b00000010) {
        return true;
    }
    return false;
}

bool Board::isBlackPawn(byte piece) {
    if((piece & 0b00001111) == 0b00000011) {
        return true;
    }
    return false;
}
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

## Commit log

2021-12-20 Added 3D printer files
    [mephisto-module-tft-35-pi-pico.FCStd, mephisto-module-tft-35-pi-pico.amf, mephisto-module-tft-35-pi-pico.stl]
2021-12-22 New partition table
    [open-mephisto.csv]
2021-12-22 Corrected partition table and added touch calib
    [open-mephisto.csv]
2021-12-23 Fixed connections and removed calibration button
    [main.cpp]
2022-01-01 adjusted wiring for new module and fixed battery symbol and glowing LEDs in Deep Sleep
    [main.cpp, mephisto.cpp, mephisto.h]
2022-01-03 new case design
2022-01-06 case converted to STL format
    [open-mephisto-module-tft-35-pi-pico-bottom.stl, open-mephisto-module-tft-35-pi-pico-cover.stl, open-mephisto-module-tft-35-pi-pico-display.stl]
2022-01-09 UI improvements and new case files
    [20220102-mephisto-modul-tft-35-v2.4-pi-pico-Bottom.amf, 20220103-mephisto-modul-tft-35-v2.4-pi-pico-Cover.amf, 20220103-mephisto-modul-tft-35-v2.4-pi-pico-Top.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]
2022-01-15 fixed error in wiring table
2022-01-23 enhanced compatibility to different boards
2022-01-26 improved LED control
2022-01-29 3D files for printing, now compatible to Modular
    [open-mephisto-module-tft-35-pi-pico-BASE.stl, open-mephisto-module-tft-35-pi-pico-COVER-SNAP.stl, open-mephisto-module-tft-35-pi-pico-SNAP-COVER.stl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]
2022-02-16 fixed Android connection problem
    [main.cpp]
2022-03-06 Version 1.3
    [open-mephisto-module-tft-35-pi-pico-BASE.stl, open-mephisto-module-tft-35-pi-pico-cover.stl, open-mephisto-module-tft-35-pi-pico-display.stl]
2022-05-16 Update mephisto.cpp
    improving board communication
2022-11-20 renamed project
    [chesstimation.csv]
2023-03-20 fixed Certabo calibration queens
    [main.cpp]
2023-12-04 implemented 2nd version of language switching
2023-12-08 implemented 3rd version of language switching
2025-10-30 Updated to LVGL 9.4.0
    [DISPLAY-VOID-fuzzy.3mf, DISPLAY-VOID-normal.3mf, chesstimation.csv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]

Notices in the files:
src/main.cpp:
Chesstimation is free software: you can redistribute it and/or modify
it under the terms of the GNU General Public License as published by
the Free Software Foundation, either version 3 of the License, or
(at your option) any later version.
